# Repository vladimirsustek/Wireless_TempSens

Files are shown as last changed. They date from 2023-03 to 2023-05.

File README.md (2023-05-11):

<h2>The BleuPill tempSens!</h2>

<h2>Intended usages</h2>
<ol>
  <li>Battery operating low-power temperature sensor</li>
  <li>PID controlled loop (PWM H-Bridge)</li>
</ol>

System consist of: <br> 
<ol>
  <li>Core MCU - STM32F103C8T6 BluePill module</li>
  <li>nRF24L01+ wireless module</li>
  <li>LM75AD temperature sensor</li>
  <li>2x NTC 10k on-board sensor</li>
  <li>Optional PWM H-Bridge DRV8220</li>
  <li>Optional self-measuring current consumption circuit (OA LMV358 1/2 sensing 10Ohm) - curr</li>
  <li>Optional OA channel sensing general purpose external voltage (LMV358 2/2) - oagp</li>
</ol>

This project has default structure for STM's [STM32CudeIDE](https://www.st.com/en/development-tools/stm32cubeide.html#:~:text=STM32CubeIDE%20is%20an%20advanced%20C,and%20GDB%20for%20the%20debugging.)
.Download this free IDE to build the project.<br/>
**The project utilizes default STM's HAL drivers**<br/>

To see complete PCB design, see "PCB_design" directory, or at least the [schematic](/PCB_design/Wireless_TempSens.pdf)

<h2>Battery operating low-power temperature sensor</h2>

System shall periodically send all measured data in specified interval.<br/>
System shall consume minimal power when not measuring or sending the data .<br/>
System shall be parametrized over the UART (115200b, LF terminated):
<ol>
  <li>nRF24L01+'s TX_ADR: 5 - bytes e.g. ADR01</li>
  <li>nRF24L01+'s RX_ADR_P0: 5 - bytes e.g. ADR01</li>
  <li>PERIOD INTERVAL: number 0 - 255 representing low power mode in seconds</li>
</ol>
Note that the UART connection is meant as optional for parametrization and logging.

<h3>BluePill modifications</h3>
Due to the permanetly on PWR LED (when connected to the 3V3)<br/>
and the PC13 LED (on due to the TAMPER RTC-ALARM PIN),<br/>
their pull-up resistors has been desoldered (R5, R1).<br/>
Note that each LED consumed cca 2mA what is inadmissible for low power mode.

<h3>Startup and operational sequence<br/></h3>
After reset, the application sends UART messages:<br/><br/>
<em>LISTENING FOR PARAMETRIZATION 10000 ms<br/>
FORMAT: ADR01 ADR01 010</em><br/>...displaying currently set parameters<br/><br/>
When a new parameters has been received and set, they are displayed:<br/><br/>
<em>TX_ADR ADR01<br/>
RX_ADR ADR01<br/>
STOP_PERIOD 58<br/>
NORMAL MODE STARTED</em><br/>
When no or invalid parameters were provided:<br/><br/>
<em>NO CHANGES APPLIED<br/>
NORMAL MODE STARTED</em/>

Then, once per pre-set interval the system sends over the UART message:<br/><br/>
<em>TMPE 23750 - the temperature by the LM75AD [m°C]<br/>
NTC2 1334 - the NTC2 measured voltage [mV]<br/>
NTC1 1392  - the NTC1 measured voltage [mV]<br/>
NTC2 8998 - the NTC2 calculated resistance [mV]<br/> 
NTC1 9768 - the NTC1 calculated voltage [mV]<br/>
NTC2 274344 - the NTC2 interpolated temperature [m°C]<br/>
NTC1 255636 - the NTC1 interpolated temperature [m°C]<br/>
OAGP 1236 - the measured voltage on the oagp [mV]<br/>
CURR 1140 - the measured voltage on the curr [mV]<br/>
TMPI 34 - the MCU internal sensor temperature [°C]<br/>
VREF 2815 - the MCU power supply VDDA [mV]<br/>
NRF STATUS: 0x1e - the STATUS register of the nRF24L01</em><br/>

And also sends over the nRF24L01+ structure consist of (wireless):<br/><br/>
<em>int32_t ntc2;<br/>
int32_t ntc1;<br/>
int32_t oagp;<br/>
int32_t curr;<br/>
int32_t tmpi;<br/>
int32_t vdda;<br/>
int32_t tmpe;</em><br/>

With the same meaning like explained for the UART message.<br/>
The ntc2 and ntc1 is already the interpolated temperature value.<br/>

<h3>Low power current consumption</h3>

<h4>LP (Low Power) - STOP_MODE the deepest MCU sleep mode</h4>

According to the the [STM32F103C8T6 datasheet](/Docs/stm32f103cb.pdf) the STOP_MODE
consumption is 14uA for the VDDA = 3.3V<br>

As the BluePill utilizes the LDO [RT9193-33](/Docs/RT9193-33PB-Richtek.pdf) with
quescient current 90-130uA and all external peripherals are<br/>controlled using the
P-FET transistor with 470kOhm pull-up (7uA) - disconnected during the STOP_MODE.<br/>

The maximal STOP_MODE consumption for VDDA = 3.3V (5V BluePill power supply) is:<br/>

<em> I_LP = I_MCU_STOP_MODE + I_LDO_QUESCIENT + I_T_PULL_UP = 14uA + 130uA + 7uA = 150uA.

<h4>ON - measuring the temperatures/voltages</h4>

The On-Mode consumption mostly consist of the:<br/>

STM32CubeIDE:PCC_Tool_Calculator MCU consumption at 2MHz clock = 1.9mA<br/>
[LM75AD](/Docs/LM75A.pdf) normal mode consumption = 100uA<br/>
NTC1 + NTC2 consumption at 25°C (10k+10k) = 2x165uA = 330uA<br/>

<em> I_ON = I_MCU+ I_LM75AD + I_NTC = 1900uA + 100uA + 330uA = 2380uA</em>

<h4>TX - nRF24L01+ transmit with 16 repeat attempts, 4000us timeout</h4>

The TX mode:<br/>
nRF24L01+ consumption in TX mode (0dBm max power):

<em> I_TX = I_ON + I_NRF_TX  = 2380uA + 13000uA = 15080</em>

The maximal time spent in TX mode for payload = 32Bytes<br/>
bits_to_transmit = preamb + address + packet control field + payload + crc<br/>
bits_to_transmit = 8 + 5*8 + 9 + 32*8 + 2*8 = 329 bits<br/>

329bits are transmitted with 2Mbps in time 329/2,000,000 = 165us<br/>

However as the ACK mode is selected (the same amount might be sent back)<br/>
the duration 330us shall be taken in account (omitted other minor latencies).<br/>

To be sure, 16 re-transmits with 4000us timeout are selected.<br/>

thus I_TX might take up to cca 16x4000 = 64ms => 100ms TX time selected.<br/>

<br/>See the [nRF24L01+](nRF24L01Pluss_Preliminary_Product_Specification_v1_0.pdf) for more info<br/>

<h4>Average consumption</h4>

The average current consumption for the operational sequence:

I_ON = 1.9 seconds<br/>
I_TX = 0.1 seconds<br/>
I_LP = 58  seconds<br/>

I_AVG = (1.9x2380uA + 0.1x15080 + 58x150uA)/60 = 245uA<br/>

As the conventional AA or AAA batteries are providing good power down to the 0.9V,<br/>
and all the used components quarantie operation down to the 2.7V (3x0.9V)<br/>

For the 1500mAh batteries, expected durability of operation is:

t = 1500 / I_AVG = 1500 / 0.245 = 6122 hours => t = 255 days

<h4>Evaluation - Measured consumption</h4>

For the 5V power supply, I_LP = 116uA<br/>
For the 2.9V power supply, I_LP = 82uA<br/>

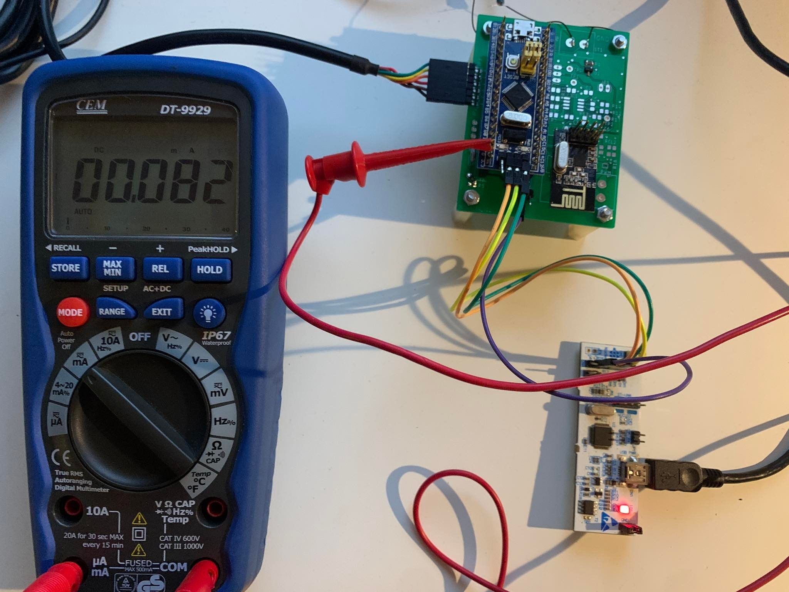
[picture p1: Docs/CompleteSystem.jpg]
Demo


**Looks like the project fullfills the requirements !!**

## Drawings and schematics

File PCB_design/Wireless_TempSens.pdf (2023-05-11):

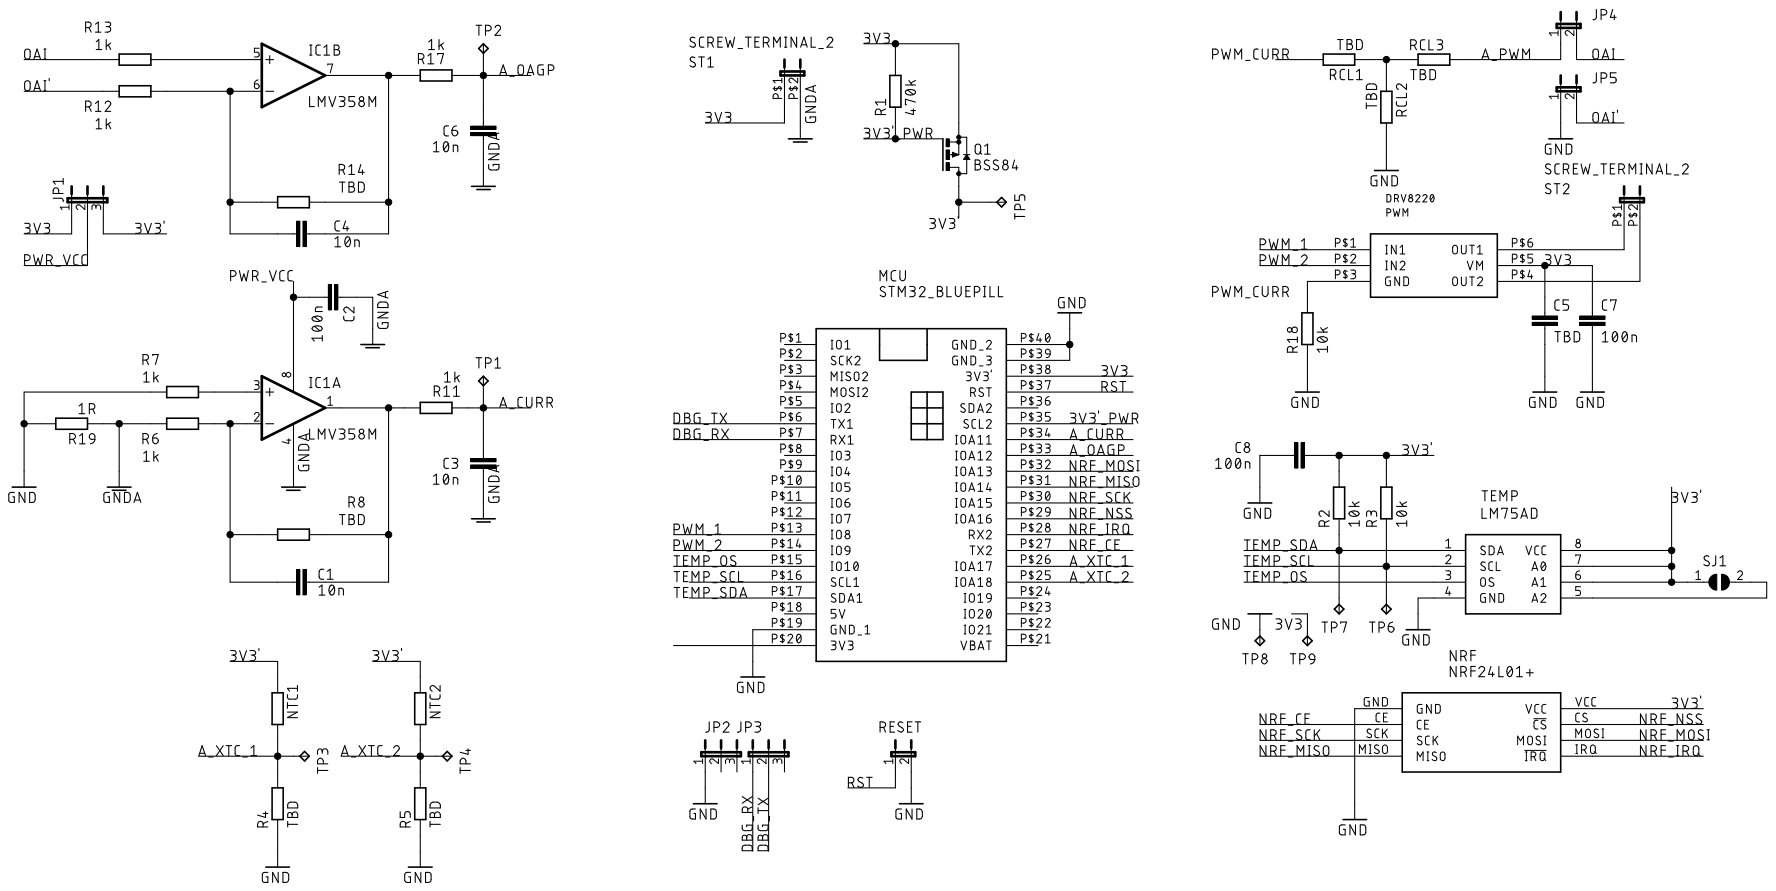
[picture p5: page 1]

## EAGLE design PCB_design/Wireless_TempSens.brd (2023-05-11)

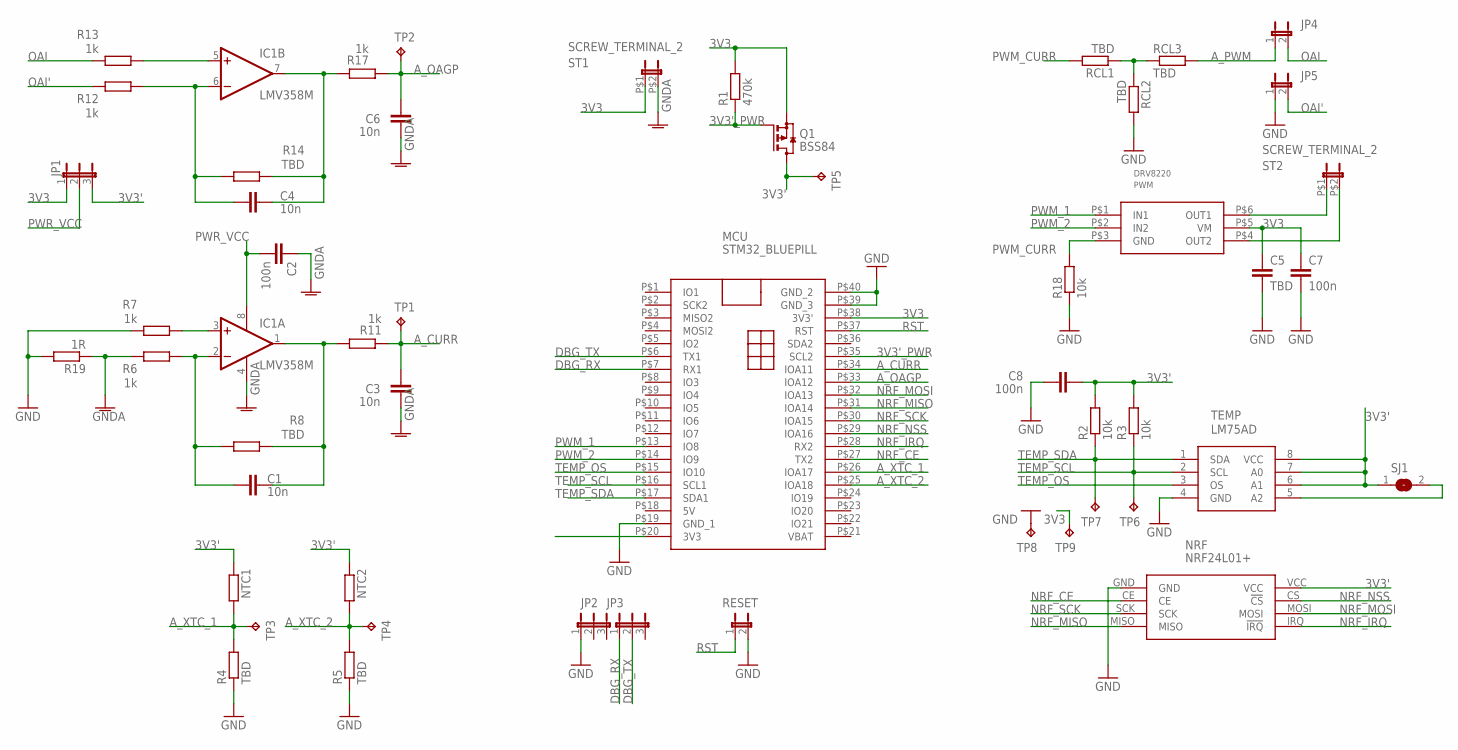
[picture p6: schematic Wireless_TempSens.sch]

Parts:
C1, C3, C4, C6: 10n; C0805
C2, C7, C8: 100n; C0805
C5: TBD; C0805
IC1: LMV358M; SO08
JP1, JP2, JP3: JP2E; JP2
JP4, JP5: JP1E; JP1
MCU: STM32_BLUEPILL
NRF: NRF24L01+
NTC1, NTC2: R-EU_0204/5; 0204/5
PWM: DRV8220; SOT-5X3
Q1: BSS84; SOT23
R1: 470k; R0805
R2, R3, R18: 10k; R0805
R4, R5, R8, R14: TBD; R0805
R6, R7, R11, R12, R13, R17: 1k; R0805
R19: 1R; R0805
RCL1, RCL2, RCL3: TBD; R0805
RESET: JP1E; JP1
SJ1: SJ
ST1, ST2: SCREW_TERMINAL_2; SCREW_TERMIANL_2
TEMP: LM75AD; SOIC8
TP1, TP2, TP3, TP4, TP5, TP6, TP7, TP8, TP9: TPPAD1-13; P1-13

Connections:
3V3: C5.1, C7.1, JP1.1, MCU.P$20 (3V3), MCU.P$38 (3V3'), PWM.P$5 (VM), Q1.2 (S), R1.2, ST1.P$1 (1), TP9.TP
3V3': C8.2, JP1.3, NRF.VCC, NTC1.1, NTC2.1, Q1.3 (D), R2.2, R3.2, SJ1.1, TEMP.6 (A1), TEMP.7 (A0), TEMP.8 (VCC), TP5.TP
3V3'_PWR: MCU.P$35 (SCL2), Q1.1 (G), R1.1
A_CURR: C3.2, MCU.P$34 (IOA11), R11.1, TP1.TP
A_OAGP: C6.2, MCU.P$33 (IOA12), R17.1, TP2.TP
A_PWM: JP4.1, RCL3.2
A_XTC_1: MCU.P$26 (IOA17), NTC1.2, R4.2, TP3.TP
A_XTC_2: MCU.P$25 (IOA18), NTC2.2, R5.2, TP4.TP
DBG_RX: JP3.1, MCU.P$7 (RX1)
DBG_TX: JP3.2, MCU.P$6 (TX1)
GND: C5.2, C7.2, C8.1, JP2.1, JP5.1, MCU.P$19 (GND_1), MCU.P$39 (GND_3), MCU.P$40 (GND_2), NRF.GND, R4.1, R5.1, R7.2, R18.1, R19.2, RCL2.2, RESET.2, TEMP.4 (GND), TP8.TP
GNDA: C2.1, C3.1, C6.1, IC1.4 (V-), R6.2, R19.1, ST1.P$2 (2)
unnamed: IC1.3 (+IN), R7.1
unnamed: C1.2, IC1.2 (-IN), R6.1, R8.2
unnamed: C1.1, IC1.1 (OUT), R8.1, R11.2
unnamed: IC1.5 (+IN), R13.1
unnamed: C4.2, IC1.6 (-IN), R12.1, R14.2
unnamed: C4.1, IC1.7 (OUT), R14.1, R17.2
unnamed: SJ1.2, TEMP.5 (A2)
unnamed: PWM.P$6 (OUT1), ST2.P$1 (1)
unnamed: PWM.P$4 (OUT2), ST2.P$2 (2)
unnamed: RCL1.1, RCL2.1, RCL3.1
NRF_CE: MCU.P$27 (TX2), NRF.CE
NRF_IRQ: MCU.P$28 (RX2), NRF.IRQ (!IRQ)
NRF_MISO: MCU.P$31 (IOA14), NRF.MISO
NRF_MOSI: MCU.P$32 (IOA13), NRF.MOSI
NRF_NSS: MCU.P$29 (IOA16), NRF.CS (!CS)
NRF_SCK: MCU.P$30 (IOA15), NRF.SCK
OAI: JP4.2, R13.2
OAI': JP5.2, R12.2
PWM_1: MCU.P$13 (IO8), PWM.P$1 (IN1)
PWM_2: MCU.P$14 (IO9), PWM.P$2 (IN2)
PWM_CURR: PWM.P$3 (GND), R18.2, RCL1.2
PWR_VCC: C2.2, IC1.8 (V+), JP1.2
RST: MCU.P$37 (RST), RESET.1
TEMP_OS: MCU.P$15 (IO10), TEMP.3 (OS)
TEMP_SCL: MCU.P$16 (SCL1), R3.1, TEMP.2 (SCL), TP6.TP
TEMP_SDA: MCU.P$17 (SDA1), R2.1, TEMP.1 (SDA), TP7.TP

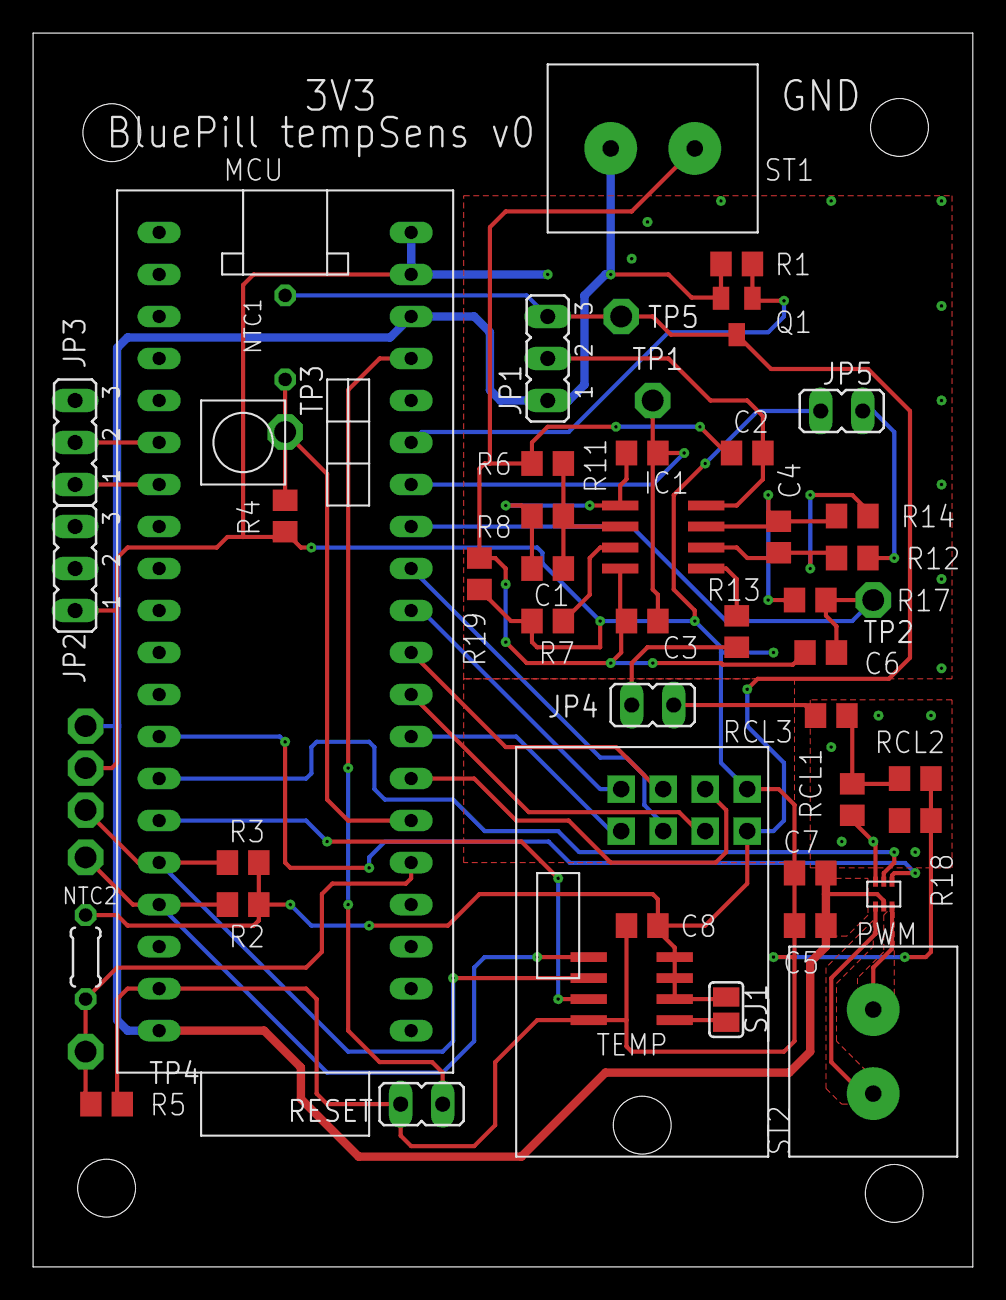
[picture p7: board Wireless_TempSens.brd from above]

Board: 2 copper layers, 56.8 x 74.6 mm, 52 parts (1 on the bottom side), 38 nets.

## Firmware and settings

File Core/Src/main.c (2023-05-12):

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
/* Includes ------------------------------------------------------------------*/
#include "main.h"
#include "adc.h"
#include "dma.h"
#include "i2c.h"
#include "rtc.h"
#include "spi.h"
#include "tim.h"
#include "usart.h"
#include "gpio.h"

/* USER CODE BEGIN Includes */
#include <string.h>
#include <assert.h>
#include <stdbool.h>

#include "cli.h"
#include "measurement_defines.h"
#include "nrf24l01p_driver.h"
#include "int_measurements.h"
#include "ext_measurements.h"

#include "stm32f1xx_hal_flash.h"
#include "stm32f1xx_hal_flash_ex.h"
/* USER CODE END Includes */

/* USER CODE BEGIN PTD */
typedef Measurement_t Payload_t;

typedef struct NVMdata
{
	char tx_adr[6];
	char rx_adr[6];
	uint8_t stop_period;
	const uint8_t padding[3];
}NVMdata_t;

/* USER CODE END PTD */

/* USER CODE BEGIN PD */
#define PARAMETRIZATION_TIMEOUT	(uint32_t)(10*1000)
#define TMPE_ATTEMPT_TIMEOUT_MS (uint32_t)(100)
#define STOP_PERIOD_MAX			(uint8_t)(255)
#define COMMAND_LNG				(uint32_t)(16)
#define TX_ADR_OFFSET 			(uint32_t)(0)
#define RX_ADR_OFFSET 			(uint32_t)(6)
#define ADR_LNG					(uint32_t)(5)
#define DLMT_1_IDX				(uint32_t)(5)
#define DLMT_2_IDX				(uint32_t)(11)
#define UNITS_IDX 				(uint32_t)(14)
#define TENS_IDX 				(uint32_t)(13)
#define HUNDREDS_IDX 			(uint32_t)(12)
#define DELIMITER				(char)(' ')
/* USER CODE END PD */


void SystemClock_Config(void);
/* USER CODE BEGIN PFP */
void Board_3V3PWR_Up();
void Board_3V3PWR_Down();
void Board_SetNextAlarm(uint8_t seconds);
void NVM_Write(uint32_t*data, uint32_t length);
void NVM_Read(uint32_t*data, uint32_t length);
int NVM_Parametrization(NVMdata_t* data);
void RTC_DisableDefaultAlarm();
void I2C_ReInitialize();
/* USER CODE END PFP */

/**
  * @brief  The application entry point.
  * @retval int
  */
int main(void)
{
  /* USER CODE BEGIN 1 */
	/* Maximal length of the payload for the NRF24L01+ is PAYLOAD_MAX*/
	static_assert(sizeof(Payload_t) <= PAYLOAD_MAX);
	/* Padding 4 for better uint32_t 'pointing'*/
	static_assert(sizeof(NVMdata_t) % 4 == 0);
	Payload_t payload = {0};
	NVMdata_t data = {0};
  /* USER CODE END 1 */

  /* MCU Configuration--------------------------------------------------------*/

  /* Reset of all peripherals, Initializes the Flash interface and the Systick. */
  HAL_Init();

  /* Configure the system clock */
  SystemClock_Config();

  /* Initialize all configured peripherals */
  MX_GPIO_Init();
  MX_DMA_Init();
  MX_SPI1_Init();
  MX_ADC1_Init();
  MX_USART1_UART_Init();
  MX_TIM3_Init();
  MX_I2C1_Init();
  MX_RTC_Init();
  /* USER CODE BEGIN 2 */

  /* Disable the default Alarm coming from the MX_RTC_Init()*/
  RTC_DisableDefaultAlarm();
  /* Get NVM data */
  NVM_Read((uint32_t*)&data, sizeof(NVMdata_t)/4);

  UART_PRINT("LISTENING FOR PARAMETRIZATION %ld ms\n", PARAMETRIZATION_TIMEOUT);
  UART_PRINT("FORMAT: %s %s %03d\n", data.tx_adr, data.rx_adr, data.stop_period);

  /* Listen for 10 seconds and try to parse the command. This Timeout also
   * prevents from MCU going into STOP MODE immediately after initialization*/
  if (!NVM_Parametrization(&data))
  {
	  UART_PRINT("NO CHANGES APPLIED\n");
  }

  UART_PRINT("NORMAL MODE STARTED\n");
  /* USER CODE END 2 */

  /* Infinite loop */
  /* USER CODE BEGIN WHILE */
  while (1)
  {
    /* USER CODE END WHILE */

    /* USER CODE BEGIN 3 */
	  /* I2C Malfunctioned after loosing 3V3 rail voltages */
	  I2C_ReInitialize();
	  /* Return from the STOP mode needs re-start the all clocks*/
	  SystemClock_Config();
	  /* Power up all external peripherals (NTCs, LM75AD, NRF24L01+, OAs)*/
	  Board_3V3PWR_Up();

	  /* Resume the tick necessary for HAL polling functions
	   * tick comes from the ARM-core */
	  HAL_ResumeTick();

	  /* Start measurements (Automatic DMA, TIM3 triggered) */
	  IntMeas_Open();

	  /* Power up NRF24L01+ chip */

	  /* Wait some time to:
	   * 1) 103ms boot up time for the NRF24L01+
	   * 2) 1/50Hz*48 = 960ms ... see IntMeas implementation */
	  HAL_Delay(960);
	  /* Configure NRF as a transmitter */
	  NRF_configure(true);
	  NRF_setTX_ADDR((uint8_t*)data.tx_adr, ADR_LNG);
	  NRF_setRX_ADDR_P0((uint8_t*)data.rx_adr, ADR_LNG);

	  /* Get the external measurements results */
	  /* Set the tmpe as an error value and try to read the .tmpe
	   * maximally for the TMPE_ATTEMPT_TIMEOUT, if any valid readout
	   * is reached, the tmpe will be simply tmpe */
	  payload.tmpe = INT32_MIN;
	  uint32_t tick  = HAL_GetTick();
	  while((payload.tmpe == INT32_MIN) &&
			  (tick + TMPE_ATTEMPT_TIMEOUT_MS > HAL_GetTick()))
	  {
		  ExtMeas_LM75AD_GetTemp(&payload);
	  }

	  /* Get the internal measurements */
	  IntMeas_Get(&payload);

	  /* Prepare NRF24L01+ payload*/
	  NRF_setW_TX_PAYLOAD((uint8_t*)&payload, sizeof(Payload_t));

	  /* Send payload and check*/
	  NRF_CEactivate();
	  HAL_Delay(100);
	  NRF_CEdeactivate();
	  UART_PRINT("NRF STATUS: 0x%02x\r\n", NRF_getSTATUS());

	  /* Disable internal measurement */
	  IntMeas_Close();
	  /* Disable all external peripherals*/
	  Board_3V3PWR_Down();
	  /* Enable wake-up timer*/
	  Board_SetNextAlarm(data.stop_period);
	  /* Disable tick to prevent wakeup - tick comes from the ARM-core*/
	  HAL_SuspendTick();
	  /* Enter low-power mode*/
	  HAL_PWR_EnterSTOPMode(PWR_LOWPOWERREGULATOR_ON, PWR_SLEEPENTRY_WFI);
  }
  /* USER CODE END 3 */
}

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
/* USER CODE BEGIN 4 */
/* Power up the 3V3 dependent external parts*/
void Board_3V3PWR_Up()
{
	HAL_GPIO_WritePin(PWR_3V3_GPIO_Port, PWR_3V3_Pin, GPIO_PIN_RESET);
}
/* Power down the 3V3 dependent external parts*/
void Board_3V3PWR_Down()
{
	HAL_GPIO_WritePin(PWR_3V3_GPIO_Port, PWR_3V3_Pin, GPIO_PIN_SET);
}

/* The empty RTC Callback, used to hit a breakpoint when the RTC interrupt fires */
void HAL_RTC_AlarmAEventCallback(RTC_HandleTypeDef *hrtc)
{
	(void)(hrtc);
}

/* Set a new alarm, algorithm just checks the RTC's time
 * and using an appropriate seconds/minutes/hours math
 * specifies the next time-point to wakeup based on the argument */
void Board_SetNextAlarm(uint8_t seconds)
{
	  RTC_DateTypeDef date = {0};
	  RTC_TimeTypeDef time = {0};
	  RTC_AlarmTypeDef alarm = {0};

	  HAL_RTC_GetTime(&hrtc, &time, RTC_FORMAT_BIN);
	  HAL_RTC_GetDate(&hrtc, &date, RTC_FORMAT_BIN);

	  time.Seconds += seconds;
	  if(time.Seconds>=60)
	  {
	  time.Minutes++;
	  time.Seconds= time.Seconds -60;
	  }
	  if(time.Minutes >= 60)
	  {
	  time.Hours++;
	  time.Minutes = time.Minutes - 60;
	  }
	  if(time.Hours > 23)
	  {
	  time.Hours = 0;
	  }
	  alarm.Alarm = RTC_ALARM_A;
	  alarm.AlarmTime.Hours = time.Hours;
	  alarm.AlarmTime.Minutes = time.Minutes;
	  alarm.AlarmTime.Seconds = time.Seconds;

	  HAL_RTC_SetAlarm_IT(&hrtc, &alarm, RTC_FORMAT_BIN);
}

int NVM_Parametrization(NVMdata_t* data)
{
	uint8_t raw_data[COMMAND_LNG] = {0};

	if(HAL_OK == HAL_UART_Receive(&huart1, raw_data, COMMAND_LNG, PARAMETRIZATION_TIMEOUT) &&
		  (raw_data[DLMT_1_IDX] == DELIMITER &&
				  raw_data[DLMT_2_IDX] == DELIMITER  &&
				  isdigit(raw_data[UNITS_IDX]) &&
				  isdigit(raw_data[TENS_IDX]) &&
				  isdigit(raw_data[HUNDREDS_IDX])))
		  {
		      /* Copy the address */
			  memcpy(data->tx_adr, raw_data + TX_ADR_OFFSET, ADR_LNG);
			  memcpy(data->rx_adr, raw_data + RX_ADR_OFFSET, ADR_LNG);
			  /* Terminate strings */
			  data->tx_adr[ADR_LNG] = '\0';
			  data->rx_adr[ADR_LNG] = '\0';

			  /* Covert string to a numbers*/
			  uint32_t raw = (raw_data[HUNDREDS_IDX] - '0')*100 +
					  (raw_data[TENS_IDX] - '0')*10 +
					  (raw_data[UNITS_IDX] - '0');

			  /* Evaluate maximal period length */
			  data->stop_period = (raw <= STOP_PERIOD_MAX) ? raw : data->stop_period;

			  /* Notify about extracted parameters */
			  UART_PRINT("TX_ADR %s\n", data->tx_adr);
			  UART_PRINT("RX_ADR %s\n", data->rx_adr);
			  UART_PRINT("STOP_PERIOD %d\n", data->stop_period);

			  /* Save to the dedicated place */
			  NVM_Write((uint32_t*)data, sizeof(NVMdata_t)/4);

			  return 1;
		  }
	else
	{
		return 0;
	}
}

void NVM_Write(uint32_t*data, uint32_t length)
{
	/* RM0008 Reference manual (STM32F103C8T6 datasheet), page 55*/
	/* [Flash-Page 127 0x0801FC00 - 0x0801FFFF] 1KB/page */
	const uint32_t PAGE_127_ADR = 0x800FC00;
	const uint32_t MAX_LENGTH = 1024;
	uint32_t adr = PAGE_127_ADR;

	FLASH_EraseInitTypeDef erase = {0};
	uint32_t error = 0;

	assert(data != NULL && length <= MAX_LENGTH);

	assert(HAL_OK == HAL_FLASH_Unlock());
	assert(HAL_OK == HAL_FLASH_OB_Unlock());

	erase.NbPages = 1;
	erase.TypeErase = FLASH_TYPEERASE_PAGES;
	erase.PageAddress = PAGE_127_ADR;

	assert(HAL_OK == HAL_FLASHEx_Erase(&erase, &error));

	for(uint32_t idx = 0; idx < length; idx++)
	{
		HAL_FLASH_Program(FLASH_TYPEPROGRAM_WORD, adr, (uint32_t)*data);
		(uint32_t*)data++;
		adr += 4;
	}

	assert(HAL_OK == HAL_FLASH_Lock());
	assert(HAL_OK == HAL_FLASH_OB_Lock());
}

void NVM_Read(uint32_t*data, uint32_t length)
{
	/* RM0008 Reference manual (STM32F103C8T6 datasheet), page 55*/
	/* [Flash-Page 127 0x0801FC00 - 0x0801FFFF] 1KB/page */
	const uint32_t PAGE_127_ADR = 0x800FC00;
	const uint32_t MAX_LENGTH = 1024;

	assert(data != NULL && length <= MAX_LENGTH);

	memcpy(data, (uint32_t*)PAGE_127_ADR, length*4);
}


void RTC_DisableDefaultAlarm()
{
	assert(HAL_OK == HAL_RTC_DeactivateAlarm(&hrtc, 0));
}

void I2C_ReInitialize()
{
	  HAL_I2C_MspDeInit(&hi2c1);
	  assert(HAL_OK == HAL_I2C_DeInit(&hi2c1));
	  MX_I2C1_Init();
}
/* USER CODE END 4 */
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


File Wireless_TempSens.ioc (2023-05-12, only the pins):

Mcu.UserName=STM32F103C8Tx
PA0-WKUP.GPIO_Label=NTC_2
PA0-WKUP.Signal=ADCx_IN0
PA1.GPIO_Label=NTC_1
PA1.Signal=ADCx_IN1
PA10.Signal=USART1_RX
PA2.GPIO_Label=NRF_CE
PA2.Signal=GPIO_Output
PA3.GPIO_Label=NRF_IRQ
PA3.Signal=GPIO_Input
PA4.GPIO_Label=NRF_NCS
PA4.Signal=GPIO_Output
PA5.GPIO_Label=NRF_SCK
PA5.Signal=SPI1_SCK
PA6.GPIO_Label=NRF_MISO
PA6.Signal=SPI1_MISO
PA7.GPIO_Label=NRF_MOSI
PA7.Signal=SPI1_MOSI
PA9.Signal=USART1_TX
PB0.GPIO_Label=OAGP
PB0.Signal=ADCx_IN8
PB1.GPIO_Label=CURR
PB1.Signal=ADCx_IN9
PB10.GPIO_Label=PWR_3V3
PB10.Signal=GPIO_Output
PB5.Signal=S_TIM3_CH2
PB6.Signal=S_TIM4_CH1
PB7.GPIO_Label=TEMP_OS
PB7.Signal=GPIO_Input
PB8.GPIO_Label=TEMP_SCL
PB8.Signal=I2C1_SCL
PB9.GPIO_Label=TEMP_SDA
PB9.Signal=I2C1_SDA
PC13-TAMPER-RTC.Signal=RTC_OUT
PC14-OSC32_IN.Signal=RCC_OSC32_IN
PC15-OSC32_OUT.Signal=RCC_OSC32_OUT
PD0-OSC_IN.Signal=RCC_OSC_IN
PD1-OSC_OUT.Signal=RCC_OSC_OUT

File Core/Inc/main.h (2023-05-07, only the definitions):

#define NTC_2_Pin GPIO_PIN_0
#define NTC_2_GPIO_Port GPIOA
#define NTC_1_Pin GPIO_PIN_1
#define NTC_1_GPIO_Port GPIOA
#define NRF_CE_Pin GPIO_PIN_2
#define NRF_CE_GPIO_Port GPIOA
#define NRF_IRQ_Pin GPIO_PIN_3
#define NRF_IRQ_GPIO_Port GPIOA
#define NRF_NCS_Pin GPIO_PIN_4
#define NRF_NCS_GPIO_Port GPIOA
#define NRF_SCK_Pin GPIO_PIN_5
#define NRF_SCK_GPIO_Port GPIOA
#define NRF_MISO_Pin GPIO_PIN_6
#define NRF_MISO_GPIO_Port GPIOA
#define NRF_MOSI_Pin GPIO_PIN_7
#define NRF_MOSI_GPIO_Port GPIOA
#define OAGP_Pin GPIO_PIN_0
#define OAGP_GPIO_Port GPIOB
#define CURR_Pin GPIO_PIN_1
#define CURR_GPIO_Port GPIOB
#define PWR_3V3_Pin GPIO_PIN_10
#define PWR_3V3_GPIO_Port GPIOB
#define TEMP_OS_Pin GPIO_PIN_7
#define TEMP_OS_GPIO_Port GPIOB
#define TEMP_SCL_Pin GPIO_PIN_8
#define TEMP_SCL_GPIO_Port GPIOB
#define TEMP_SDA_Pin GPIO_PIN_9
#define TEMP_SDA_GPIO_Port GPIOB

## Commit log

2023-03-10 Functional NRF24L01+, ADC internal measurements
2023-03-11 Operational sensor ready for server debug
2023-03-12 Added DEBUG_PRINT, fixed paths, observing ADC indexing offset
    [main.c, measurements.c]
2023-04-24 Porting to the BluePill tempSens v0, int ADC ok, LM75AD ok
2023-04-27 Added minus temperatures for LM75AD
2023-05-07 DEBUG release, 130uA STOP mode, 58s period
    [Wireless_TempSens Debug.cfg]
2023-05-12 Bugfixing (I2C stable, corrected internal temperature)
    [Wireless_TempSens.ioc, ext_measurements.c, int_measurements.c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]

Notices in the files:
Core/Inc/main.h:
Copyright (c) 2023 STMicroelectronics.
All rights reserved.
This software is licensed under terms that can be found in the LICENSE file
